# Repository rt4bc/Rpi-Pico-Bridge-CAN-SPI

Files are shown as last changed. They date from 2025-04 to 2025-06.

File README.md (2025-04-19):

# CAN to SPI Controller Based on MCP2518FD and Raspberry Pi Pico

## Description

This project is a CAN-to-SPI controller built using the MCP2518FD CAN controller and the Raspberry Pi Pico (RP2040). It allows communication between CAN and SPI-enabled devices, making it useful for embedded applications, automotive networks, and industrial control systems.

RP2040's SPI1&I2C1 defaualt configured as a controller, which make it possbile bridge the CAN bus and other SPI&I2C peripherals.

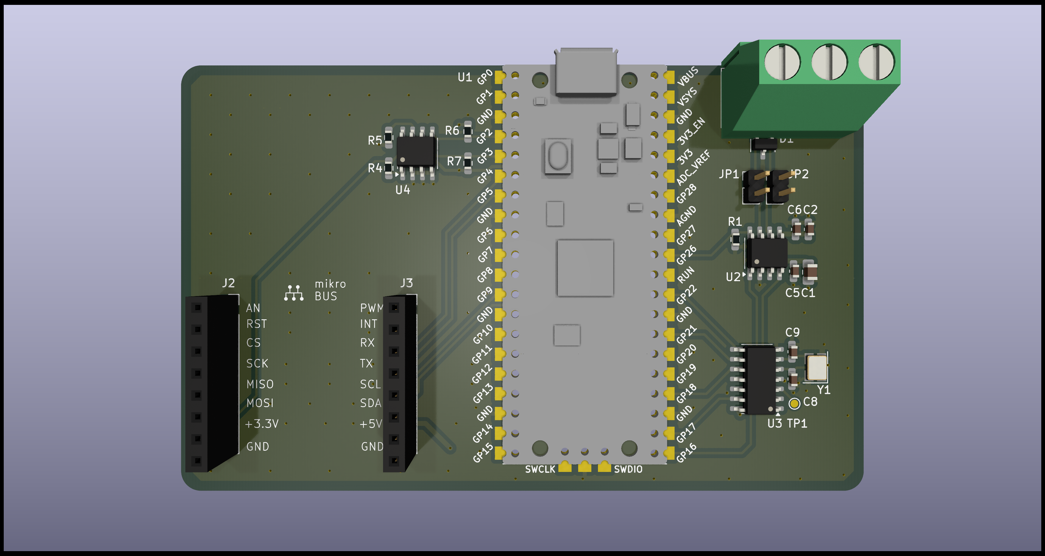
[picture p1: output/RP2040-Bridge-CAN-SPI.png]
RP2040-CAN-Bridge


## Features
- Built with Raspberry Pi Pico (RP2040) and MCP2518FD
- RP2040 SPI1 as SPI controller which can communicate with mikro interface
- RP2040 SPI0 as SPI controller which works with MCP2518FD
- CAN FD support (up to 8 Mbps)
- Supports standard and extended CAN IDs
- Configurable bit rates and filters

## Hardware Requirements

- Raspberry Pi Pico (RP2040)
- MCP2518FD CAN controller with SPI interface
- Power supply (3.3V/5V depending on CAN transceiver)
- Optional: CAN bus terminator (120Ω)

## Software Setup

1. Clone this fw repository.
2. Use PC GUI 

## Usage

Send SPI commands to the Pico, which will translate and forward them to the CAN bus via MCP2518FD. Incoming CAN messages are forwarded back to the host via SPI.

## TODO

- CAN Bus GUI Tools
- USB configure tools

---

# 基于 MCP2518FD 和 Raspberry Pi Pico 的 CAN 转 SPI 控制器

## 项目简介

本项目基于 MCP2518FD CAN 控制器和 Raspberry Pi Pico（RP2040）实现了一个 CAN 到 SPI 的通信控制器。该控制器可以实现 CAN 与 SPI 设备之间的通信，广泛适用于嵌入式系统、汽车网络以及工业控制系统。

## 功能特点

- 支持 CAN FD（速率最高达 8 Mbps）
- SPI 接口连接主控系统
- 支持标准帧和扩展帧格式
- 可配置的波特率与过滤器
- 采用 Raspberry Pi Pico 和 MCP2518FD 芯片

## 硬件需求

- Raspberry Pi Pico（RP2040）
- MCP2518FD（SPI接口）
- 电源（3.3V 或 5V，视 CAN 收发器而定）
- 可选：CAN 总线终端电阻（120Ω）

## 软件配置

1. 克隆本项目代码。
3. 将主控设备通过 SPI 接口连接到 Pico。
4. 使用 SPI 库与 Pico 通信并发送/接收 CAN 消息。

## 使用说明

主控系统通过 SPI 向 Pico 发送命令，Pico 再通过 MCP2518FD 将其转发至 CAN 总线。同时，CAN 总线接收到的数据也会被 Pico 通过 SPI 回传至主控系统。

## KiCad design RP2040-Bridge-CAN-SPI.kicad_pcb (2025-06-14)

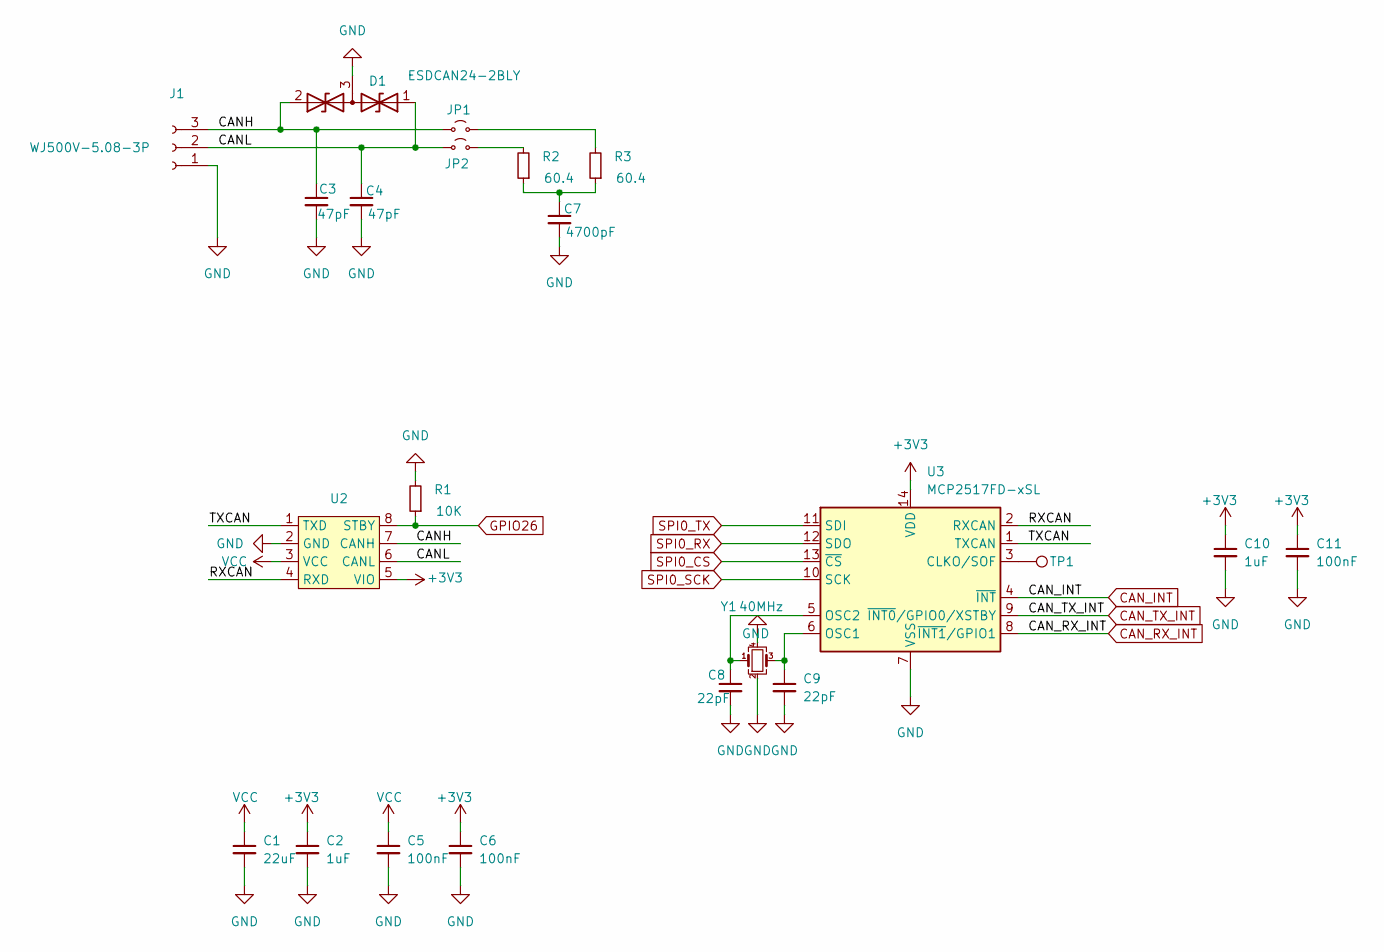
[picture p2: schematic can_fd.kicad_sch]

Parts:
C1: 22uF; C_0805_2012Metric_Pad1.18x1.45mm_HandSolder
C2, C10: 1uF; C_0603_1608Metric_Pad1.08x0.95mm_HandSolder
C3, C4: 47pF; C_0603_1608Metric_Pad1.08x0.95mm_HandSolder
C5, C6, C11: 100nF; C_0603_1608Metric_Pad1.08x0.95mm_HandSolder
C7: 4700pF; C_0603_1608Metric_Pad1.08x0.95mm_HandSolder
C8, C9: 22pF; C_0603_1608Metric_Pad1.08x0.95mm_HandSolder
D1: ESDCAN24-2BLY; SOT-23-3
J1: Conn_01x03_Socket; TerminalBlock_bornier-3_P5.08mm
JP1, JP2: Jumper_2_Small_Open; PinHeader_1x02_P2.00mm_Vertical
R1: 10K; R_0603_1608Metric_Pad0.98x0.95mm_HandSolder
R2, R3: 60.4; R_0603_1608Metric_Pad0.98x0.95mm_HandSolder
TP1: TestPoint; TestPoint_Pad_D1.0mm
U2: High-speed CAN FD Transceiver with Standby Mode a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; SOIC-8_3.9x4.9mm_P1.27mm
U3: MCP2517FD-xSL; SOIC-14_3.9x8.7mm_P1.27mm
Y1: 40MHz; Crystal_SMD_SeikoEpson_TSX3225-4Pin_3.2x2.5mm

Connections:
+3V3: C2.1, C6.1, C10.1, C11.1, U2.5 (VIO), U3.14 (VDD); also elsewhere on the board
/CAN-FD-Interface/CANH: C3.1, D1.2 (A2), J1.3, JP1.1 (A), U2.7 (CANH)
/CAN-FD-Interface/CANL: C4.1, D1.1 (A1), J1.2, JP2.1 (A), U2.6 (CANL)
/CAN-FD-Interface/RXCAN: U2.4 (RXD), U3.2 (RXCAN)
/CAN-FD-Interface/TXCAN: U2.1 (TXD), U3.1 (TXCAN)
CAN_INT: U3.4 (~INT); also elsewhere on the board
CAN_RX_INT: U3.8 (~INT1/GPIO1); also elsewhere on the board
CAN_TX_INT: U3.9 (~INT0/GPIO0/XSTBY); also elsewhere on the board
GND: C1.2, C2.2, C3.2, C4.2, C5.2, C6.2, C7.2, C8.2, C9.2, C10.2, C11.2, D1.3 (common), J1.1, R1.2, U2.2 (GND), U3.7 (VSS), Y1.2, Y1.4; also elsewhere on the board
GPIO26: R1.1, U2.8 (STBY); also elsewhere on the board
unnamed: C7.1, R2.1, R3.1
unnamed: JP1.2 (B), R3.2
unnamed: JP2.2 (B), R2.2
unnamed: TP1.1, U3.3 (CLKO/SOF)
unnamed: C9.1, U3.6 (OSC1), Y1.3
unnamed: C8.1, U3.5 (OSC2), Y1.1
SPI0_CS: U3.13 (~CS); also elsewhere on the board
SPI0_RX: U3.12 (SDO); also elsewhere on the board
SPI0_SCK: U3.10 (SCK); also elsewhere on the board
SPI0_TX: U3.11 (SDI); also elsewhere on the board
VCC: C1.1, C5.1, U2.3 (VCC); also elsewhere on the board

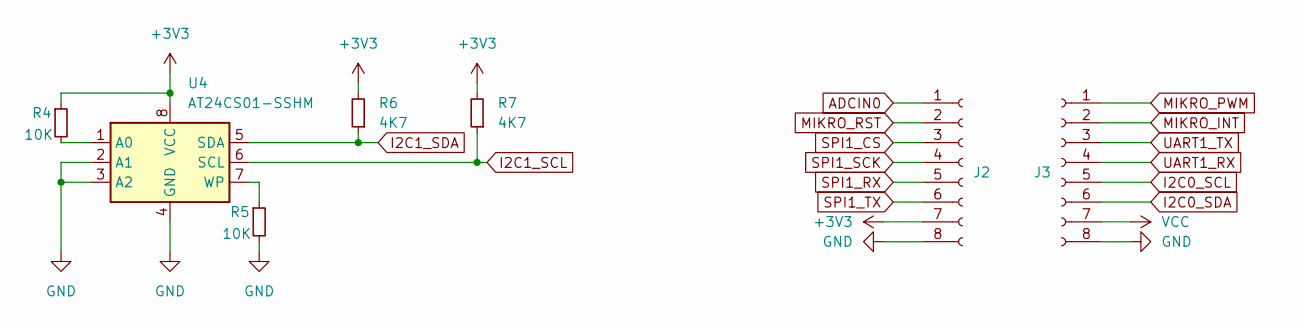
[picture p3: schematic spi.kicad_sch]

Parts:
J2, J3: Conn_01x08_Socket; PinSocket_1x08_P2.54mm_Vertical
R4, R5: 10K; R_0603_1608Metric_Pad0.98x0.95mm_HandSolder
R6, R7: 4K7; R_0603_1608Metric_Pad0.98x0.95mm_HandSolder
U4: AT24CS01-SSHM; SOIC-8_3.9x4.9mm_P1.27mm

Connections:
+3V3: J2.7, R4.1, R6.2, R7.2, U4.8 (VCC); also elsewhere on the board
ADCIN0: J2.1
GND: J2.8, J3.8, R5.2, U4.2 (A1), U4.3 (A2), U4.4 (GND); also elsewhere on the board
I2C0_SCL: J3.5; also elsewhere on the board
I2C0_SDA: J3.6; also elsewhere on the board
I2C1_SCL: R7.1, U4.6 (SCL); also elsewhere on the board
I2C1_SDA: R6.1, U4.5 (SDA); also elsewhere on the board
MIKRO_INT: J3.2; also elsewhere on the board
MIKRO_PWM: J3.1; also elsewhere on the board
MIKRO_RST: J2.2; also elsewhere on the board
unnamed: R4.2, U4.1 (A0)
unnamed: R5.1, U4.7 (WP)
SPI1_CS: J2.3; also elsewhere on the board
SPI1_RX: J2.5; also elsewhere on the board
SPI1_SCK: J2.4; also elsewhere on the board
SPI1_TX: J2.6; also elsewhere on the board
UART1_RX: J3.4; also elsewhere on the board
UART1_TX: J3.3; also elsewhere on the board
VCC: J3.7; also elsewhere on the board

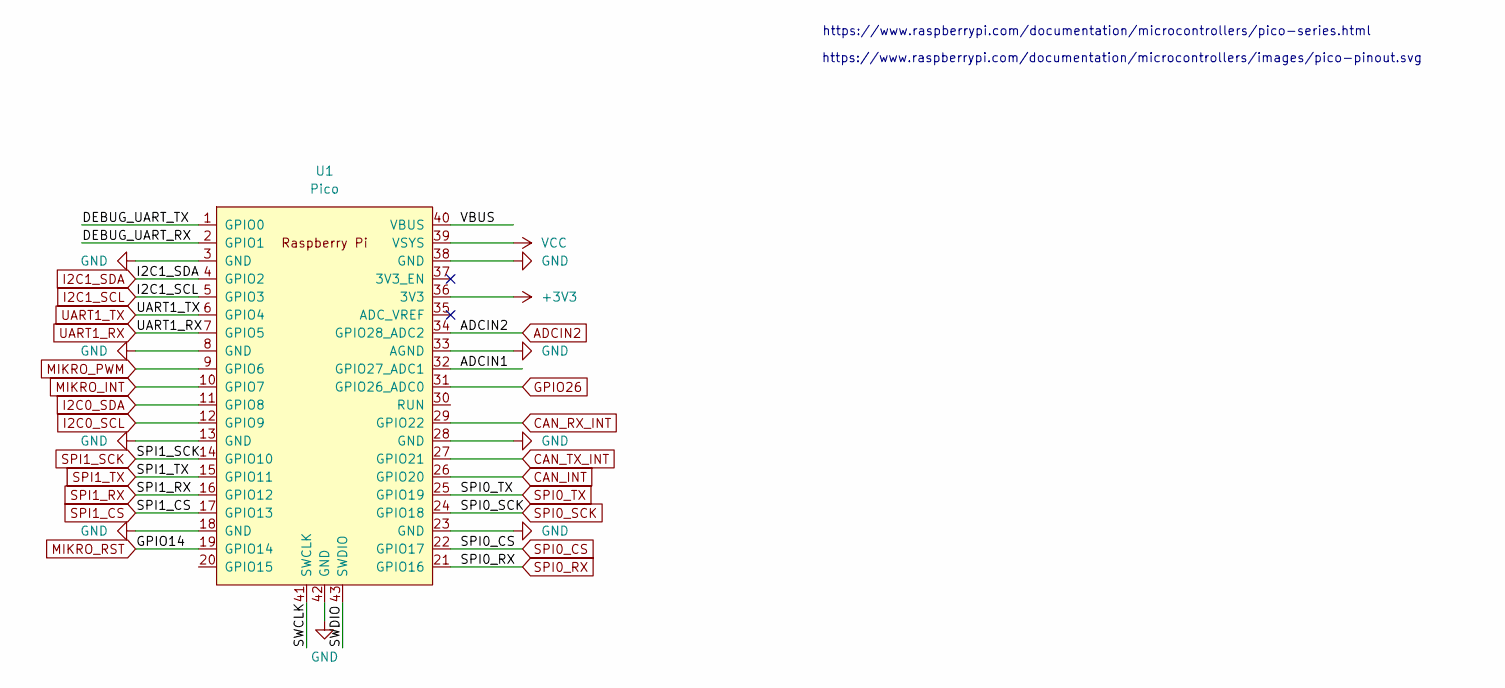
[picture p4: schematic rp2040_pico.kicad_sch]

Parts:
U1: Pico; RPi_Pico_SMD_TH

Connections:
+3V3: U1.36 (3V3); also elsewhere on the board
/RP2040-Pico/ADCIN1: U1.32 (GPIO27_ADC1)
/RP2040-Pico/DEBUG_UART_RX: U1.2 (GPIO1)
/RP2040-Pico/DEBUG_UART_TX: U1.1 (GPIO0)
/RP2040-Pico/SWCLK: U1.41 (SWCLK)
/RP2040-Pico/SWDIO: U1.43 (SWDIO)
/RP2040-Pico/VBUS: U1.40 (VBUS)
ADCIN2: U1.34 (GPIO28_ADC2)
CAN_INT: U1.26 (GPIO20); also elsewhere on the board
CAN_RX_INT: U1.29 (GPIO22); also elsewhere on the board
CAN_TX_INT: U1.27 (GPIO21); also elsewhere on the board
GND: U1.3 (GND), U1.8 (GND), U1.13 (GND), U1.18 (GND), U1.23 (GND), U1.28 (GND), U1.33 (AGND), U1.38 (GND), U1.42 (GND); also elsewhere on the board
GPIO26: U1.31 (GPIO26_ADC0); also elsewhere on the board
I2C0_SCL: U1.12 (GPIO9); also elsewhere on the board
I2C0_SDA: U1.11 (GPIO8); also elsewhere on the board
I2C1_SCL: U1.5 (GPIO3); also elsewhere on the board
I2C1_SDA: U1.4 (GPIO2); also elsewhere on the board
MIKRO_INT: U1.10 (GPIO7); also elsewhere on the board
MIKRO_PWM: U1.9 (GPIO6); also elsewhere on the board
MIKRO_RST: U1.19 (GPIO14); also elsewhere on the board
SPI0_CS: U1.22 (GPIO17); also elsewhere on the board
SPI0_RX: U1.21 (GPIO16); also elsewhere on the board
SPI0_SCK: U1.24 (GPIO18); also elsewhere on the board
SPI0_TX: U1.25 (GPIO19); also elsewhere on the board
SPI1_CS: U1.17 (GPIO13); also elsewhere on the board
SPI1_RX: U1.16 (GPIO12); also elsewhere on the board
SPI1_SCK: U1.14 (GPIO10); also elsewhere on the board
SPI1_TX: U1.15 (GPIO11); also elsewhere on the board
UART1_RX: U1.7 (GPIO5); also elsewhere on the board
UART1_TX: U1.6 (GPIO4); also elsewhere on the board
VCC: U1.39 (VSYS); also elsewhere on the board

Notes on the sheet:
https://www.raspberrypi.com/documentation/microcontrollers/pico-series.html
https://www.raspberrypi.com/documentation/microcontrollers/images/pico-pinout.svg

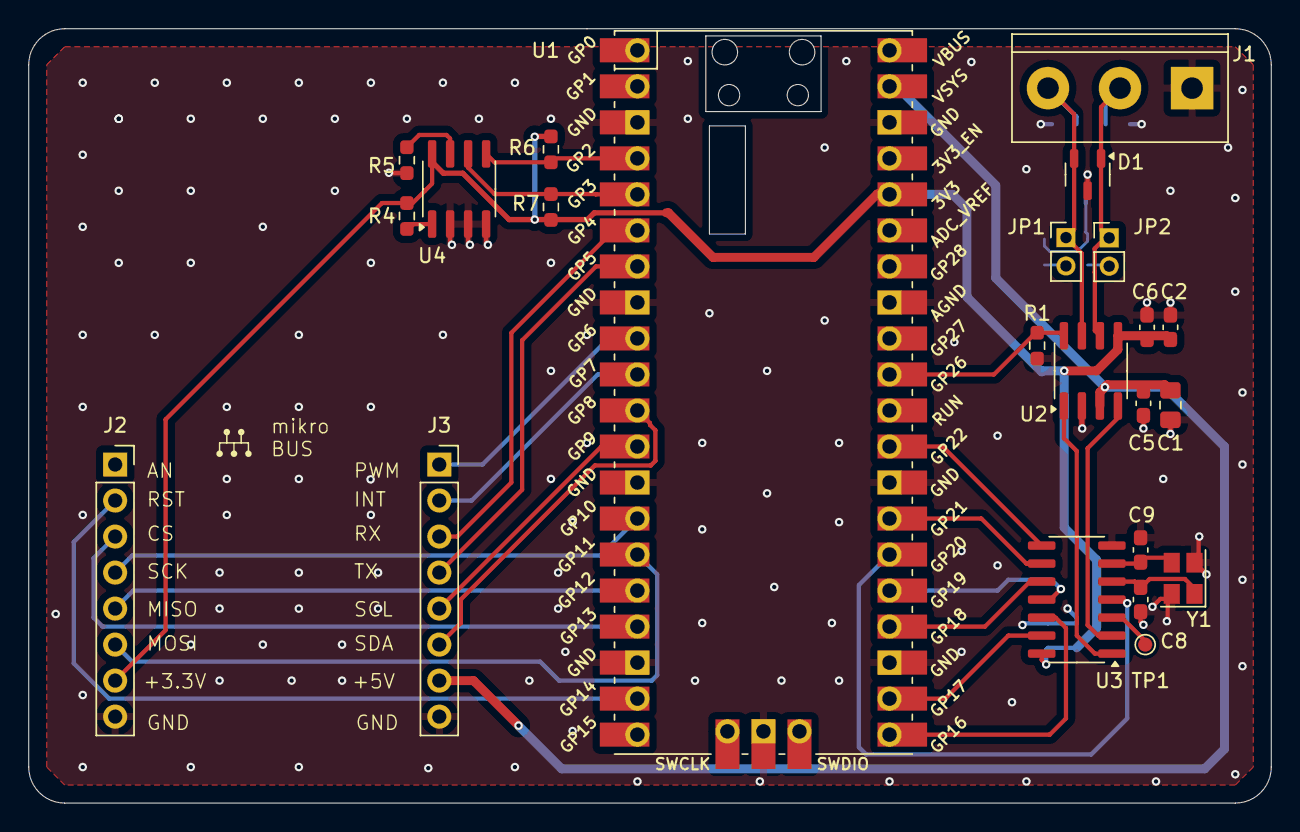
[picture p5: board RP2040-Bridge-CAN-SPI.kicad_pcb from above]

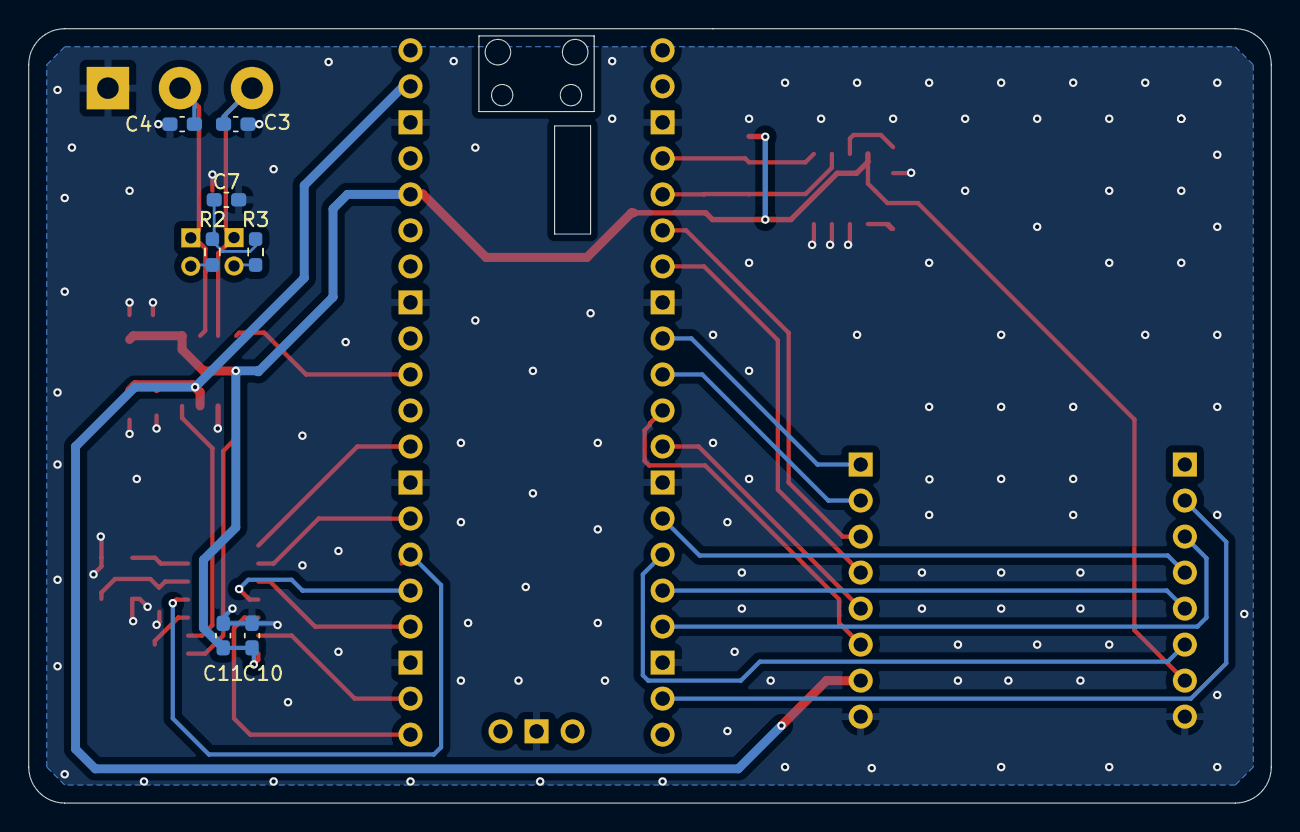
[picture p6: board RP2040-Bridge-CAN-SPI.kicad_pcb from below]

Board: 2 copper layers, 87.6 x 54.6 mm, 30 parts (7 on the bottom side), 36 nets.

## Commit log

2025-04-19 update design
    [RP2040-Bridge-CAN-SPI.kicad_pcb, RP2040-Bridge-CAN-SPI.kicad_sch, RPI-PICO-R3a-PUBLIC.brd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]
2025-04-19 udpate readme & pcb png pics
    [RP2040-Bridge-CAN-SPI.kicad_pcb]
